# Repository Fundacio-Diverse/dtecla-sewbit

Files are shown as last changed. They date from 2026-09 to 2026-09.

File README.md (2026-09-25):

# sew:bit
## Una placa de expansión de código abierto que amplía las posibilidades del micro:bit para la informática textil y los dispositivos wearables en la educación primaria (K-6)
Sew:bit es una placa de expansión de código abierto para el BBC micro:bit, diseñada en el marco de un Fab Lab para facilitar la creación de dispositivos wearables y textiles electrónicos en la educación primaria (de infantil a 6.º de primaria).

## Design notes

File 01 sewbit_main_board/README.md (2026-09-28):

## Diseño
La placa sew:bit está diseñada usando el EDA open source Kicad en su versión 8.0. En la carpeta Diseño podréis encontrar el editable del mismo, así como el svg de las serigrafía.

Para más información sobre [Kicad](https://www.kicad.org/).

## Producción
La placa se puede fabricar en cualquier casa de fabricación de pcbs, los gerber que hay en la carpeta son los requeridos por JLCPCB en su [guía para exportar archivos de producción en Kicad 8](https://jlcpcb.com/help/article/how-to-generate-gerber-and-drill-files-in-kicad-8).

El edge connector de micro:bit SMD no está disponible, al menos a fecha de Junio 2026, en la lista de partes de JLCPCB y se ha de comprar independientemente, nosotros hemos probado:

- [Sparkfun](https://www.digikey.es/es/products/detail/sparkfun-electronics/17253/13282853)
- [Aliexpress](https://es.aliexpress.com/item/1005008738053304.html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)

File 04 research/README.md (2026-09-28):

Papers:
FAB 26 @Boston - Leirado, J., Domínguez, X., & Fuentemilla, S. (2026, July 31). Sew:bit: An Open-Source Expansion Board Extending the micro:bit for E-Textile and Wearable Computing in K-6 Education. Fab 26 "Reimagine the Future" Research Papers (FAB26), Cambridge, MA, USA. https://doi.org/10.5281/zenodo.21712564

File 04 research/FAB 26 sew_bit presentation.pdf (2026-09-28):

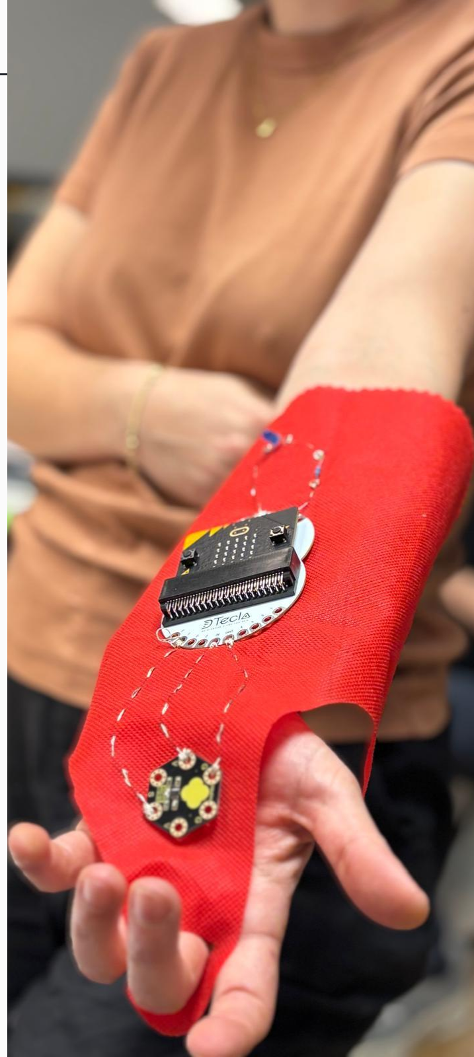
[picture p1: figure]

Julia Leirado - IAAC / Fab Lab Barcelona

# sew:bit

## An Open-Source Expansion Board Extending the micro:bit for E-Textile and Wearable Computing in K-6 Education

Xavier Domínguez - Fundació Diverse

Santiago Fuentemilla - IAAC / Fab Lab Barcelona

Micro:bit - E‑textiles - K-6 - Open hardware - Physical computing education - Digital Fabrication - Computational Making

Leirado, Domínguez & Fuentemilla (2026) — Design case study

# Contents

# Purpose of the paper

# Design/ methodology/ approach

# Data Sample

# Research limitations

# Practical implications

# Original value

Company Name | 2
01 | 05

02

03

06

07

# Findings

04

# Takeaway

08

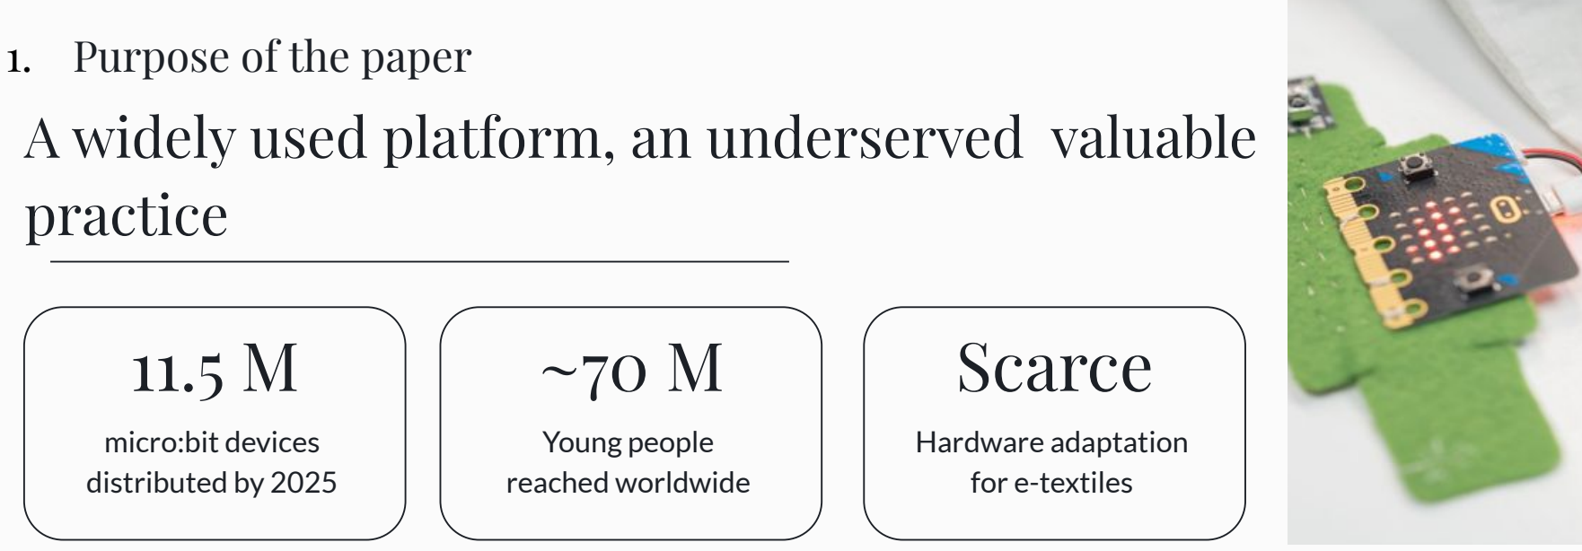
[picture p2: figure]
micro:bit devices distributed by 2025; 1. Purpose of the paper; practice; Young people reached worldwide; Hardware adaptation for e-textiles; Scarce

Leirado, Domínguez & Fuentemilla (2026) — Design case study | 3

# A widely used platform, an underserved valuable

E-textiles are a powerful route to equitable STEAM, engaging diverse learners — especially girls — by blending craft with code and circuitry (Buechley 2008; Rode 2015).

Yet the BBC micro:bit — the most adopted K-6 physical-computing platform — lacks hardware designed for textile-based making. LilyPad, Flora and Circuit Playground shaped wearable computing, but none adapt the micro:bit for the classroom stock schools already own.

Option | Pros | Cons
No additional components needed | Limited to 3 pins Board becomes permanent (must cut stitches to repurpose)

### Direct sewing of exposed connectors

Reusable: connect/disconnect BBC micro:bit without cutting stitches

### Crocodile clips (Kitronik)

### SewSimple (Feng et

al., 2025)

Flexible fabric extension for wearable integration
Large through-hole (TH) pads for beginner needles

Limited to 3 pins
Narrow holes incompatible with large beginner sewing needles

Limited to 3 pins
Not commercially available (Research)

# 1. Purpose of the paper

# No optimal way to adapt the micro:bit for e-textiles

### Keyestudio Honeycomb kit

Edge connector for reusability 10 pins for sensors/actuators Wide sensor/actuator range

Bottom connectors cause forward tilt (BBC micro:bit weight hinders wearables)
Some sensors redundant or too advanced for K-9 Missing beginner-friendly sensors

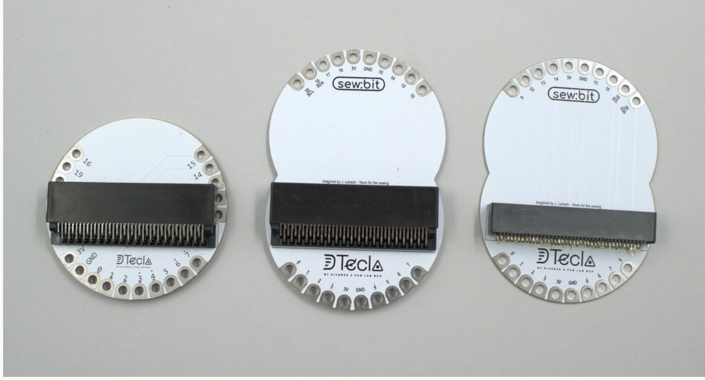
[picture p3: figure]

Sew:bit board | An open‑source expansion board that adapts the micro:bit for textile‑based making.

## Documented design case

| Iterative development within a Fab Lab context: decisions, failures, fixes.
Early findings | From deployments with K-6 students, teachers and makers on usability, accessibility and pedagogy.

01
02
03

# 1. Purpose of the paper

# Contribution of the paper

# 2. Design/ methodology/ approach

# A design case study, not a controlled evaluation

Iterative cycles of design → fabrication → workshop → reflection.
Iteration, repair and adaptation are treated as sources of design knowledge (Boling, 2010).
3 full cycles over 1 year, each: problem analysis · prototyping · workshop enactment · redesign.

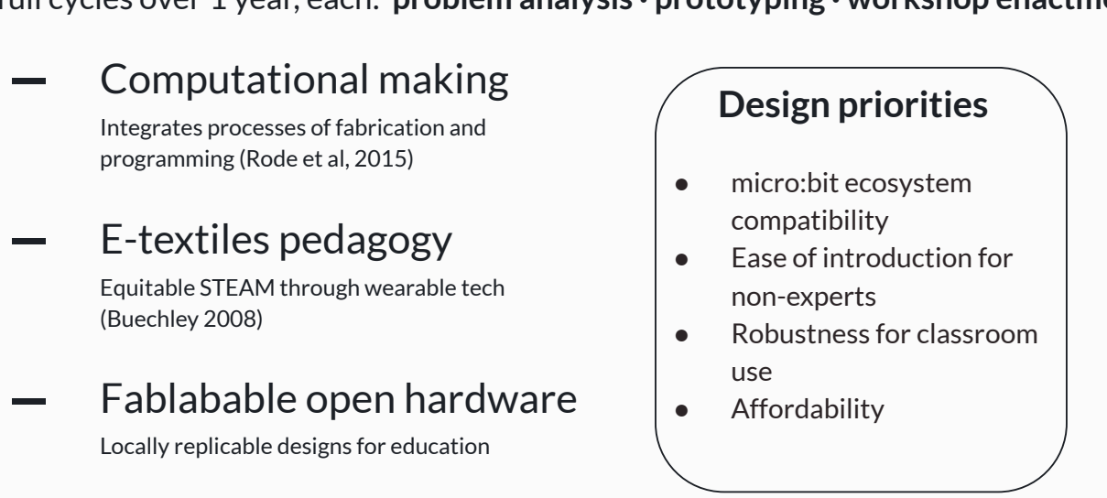
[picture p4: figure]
Computational making; Integrates processes of fabrication and programming (Rode et al, 2015); E-textiles pedagogy; Fablabable open hardware; Equitable STEAM through wearable tech (Buechley 2008); Locally replicable designs for education; ● micro:bit ecosystem compatibility ● Ease of introduction for non-experts ● Robustness for classroom use ● Affordability; Design priorities
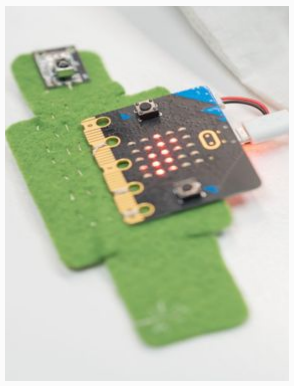
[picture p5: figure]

# 2. Design/ methodology/ approach

# Cycle 1: basic shield - Form factor first : a circular, sewable shield

- Aesthetics & accessibility — craft look (à la LilyPad); easy edge-connector insert/removal for multi-project reuse.
- Physical layout — circular shape → traces radiate from centre, spacing pads and reducing shorts.
- Sewability — oversized pads for large-hole needles; crocodile-clip friendly.

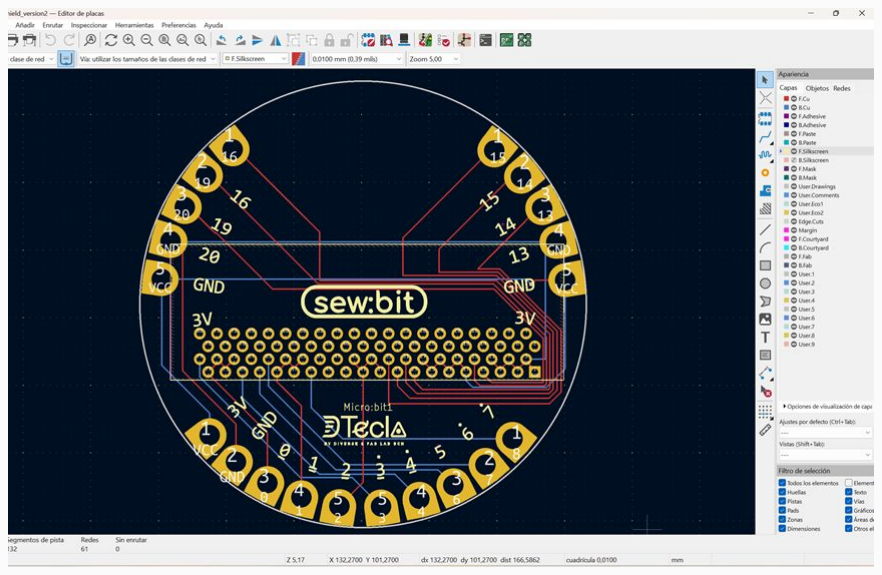
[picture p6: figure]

Workshop findings:
- TH edge connector too fine to mill locally → outsourced.
- Footprint error,
- pin occlusion,
- unstable on fabric.
- 10 prototypes.

Design - fabrication workflow:

# 2. Design/ methodology/ approach

# Cycle 2: two intersecting circles, top/bottom pins

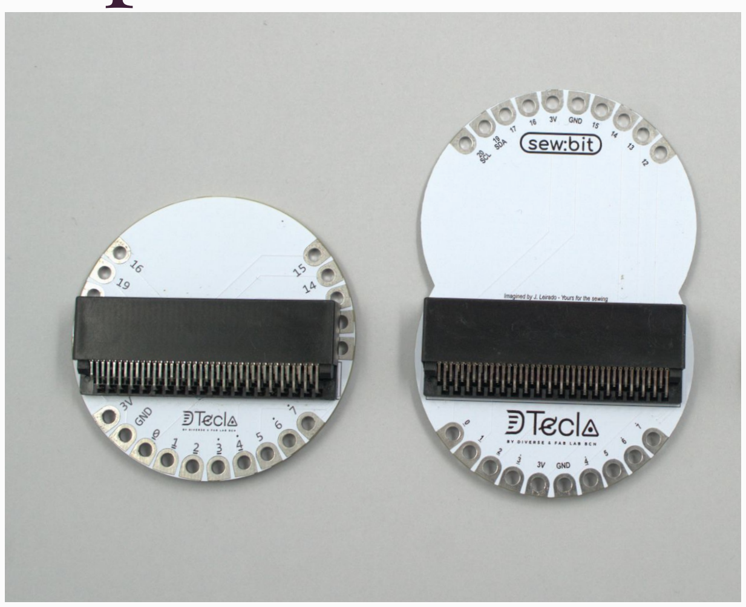
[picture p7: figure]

- Thinner board 1.6 → 1 mm (−37.5%) for a lighter feel.
- New shape from two intersecting circles — exposes all pins, keeps rounded aesthetics.
- Top/bottom split pins anchor stitching and stop forward tilt.
- Side gap holds a LiPo battery by geometry alone.

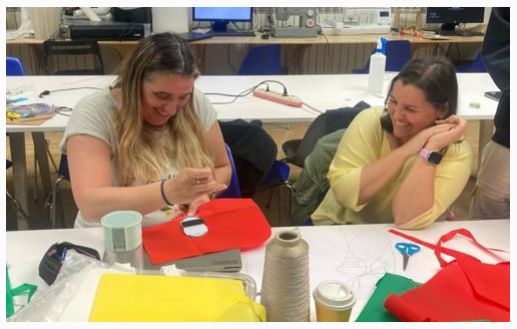
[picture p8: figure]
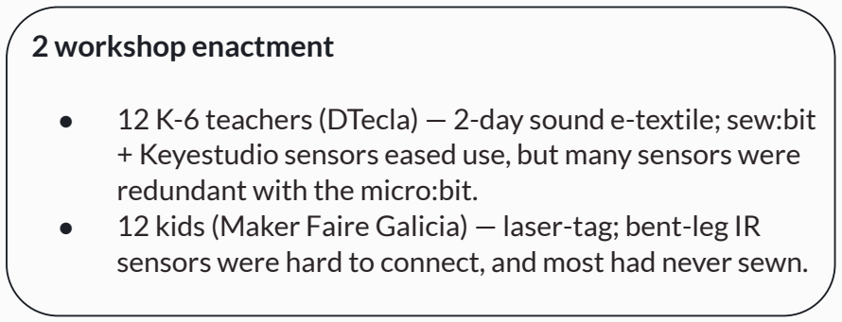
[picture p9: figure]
2 workshop enactment; redundant with the micro:bit.

- 12 K-6 teachers (DTecla) — 2-day sound e-textile; sew:bit + Keyestudio sensors eased use, but many sensors were
- 12 kids (Maker Faire Galicia) — laser-tag; bent-leg IR sensors were hard to connect, and most had never sewn.

# 2. Design/ methodology/ approach

# Cycle 3: Locally fabricable, with a sensor kit + perforated

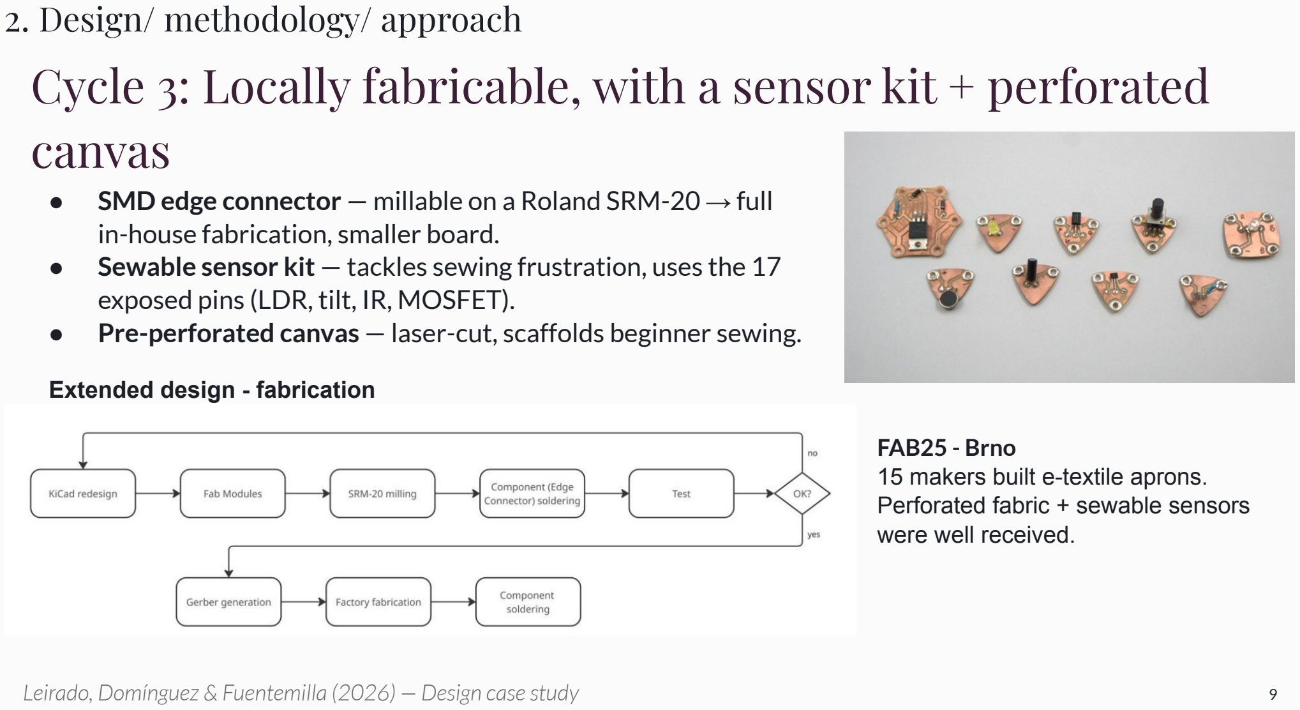
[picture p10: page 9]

# canvas

- SMD edge connector — millable on a Roland SRM-20 → full in-house fabrication, smaller board.
- Sewable sensor kit — tackles sewing frustration, uses the 17 exposed pins (LDR, tilt, IR, MOSFET).
- Pre-perforated canvas — laser-cut, scaffolds beginner sewing.

FAB25 - Brno
15 makers built e-textile aprons. Perforated fabric + sewable sensors were well received.

Extended design - fabrication workflow:

# 3. Data sample

# Workshop contexts as sources of design reflection

No formal data-collection study. Observations, informal conversations and workshop notes were used descriptively to inform each redesign.

Cycle | Pros | Participants
Cycle 1 | Fab Lab Bcn / Fundació Diverse staff | 3
Cycle 2.1 | K-6 teachers (Dtecla)
Cycle 2.2 | Children (Maker Faire Galicia)

12

12

Cycle 3 | Maker community (FAB25) | 15

## Workshop purpose

Internal prototype testing & design refinement

Explore classroom-oriented e-textiles

Explore beginner use of the prototype

Explore fablable sensor & board use

# 4. Findings

# Four recurring design insights

Hardware
usability &
sewability

Learning &
engagement

02

Classroom
integration &
scaffolding

03

Fab Lab reception
& replication
01 | 04

By Cycle 3,
pre-perforated fabric
+ dedicated sewable
sensors reduced
shorts — reliable
circuits within
1.5-hour workshops.

Teachers felt
confident to reuse
the board; kids
personalised
laser-tag wearables;
makers built diverse
apron interactions.

Teachers valued
micro:bit
compatibility but
flagged time limits,
need for
pre-packaged kits
and basic sewing
gaps.

Fab25 makers
responded positively
and asked for full
docs:
KiCad/Gerber/BOM,
lesson plans,
parametric files.

# 5. Research limitations

# Situated insights, not generalizable results

## Bounds of this work

- Workshops sat within
connected Fab Lab / maker
networks, not independent
schools.
- Modest number of enactments — no controlled comparison or statistical generalization.
- Prototype stage: not studied at manufacturing scale or in
longitudinal classroom use.

## Where to go next

- Deploy across a broader, more diverse range of Fab
Labs and schools.
- Formal classroom studies with a clear methodology.
- Comparative testing against commercial kits.
- Longitudinal use + reflections from teachers, makers and
children.

# 6. Practical implications

# What sew:bit offers each audience

Fablab & makerspaces | SMD connector → full in-house milling of double-sided boards. Download the complete repo (KiCad, Gerber, BOM, assembly) and adapt to regional parts.
K-6 classroom teachers | Extends existing micro:bit inventory — minimal new purchases. A learning journey from perforated-fabric sensor projects to curriculum-integrated work.

## micro:bit e-textiles designers

| Four transferable design principles to guide future wearable hardware for the micro:bit.

01
02
03

# 6. Practical implications

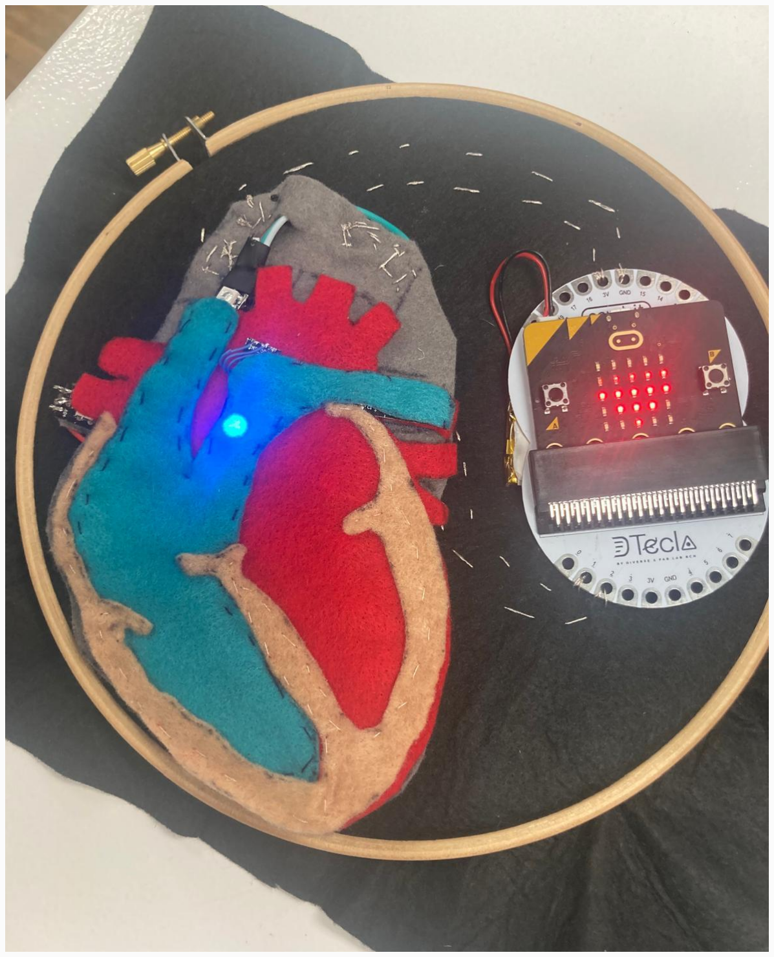
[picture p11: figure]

# What we'd tell the next hardware designer

- Top/bottom pin distribution: Prevents forward tilt; keeps natural fabric drape when sewn.
- Oversized sewable pads (≥3 mm): Fit large-hole beginner needles and crocodile clips for prototyping.
- Millable SMD edge connector: Enables local Fab Lab production (Roland SRM-20 compatible).
- Modular sensor kits: Ready-to-sew sensors optimised for pedagogical projects; less improvisation.

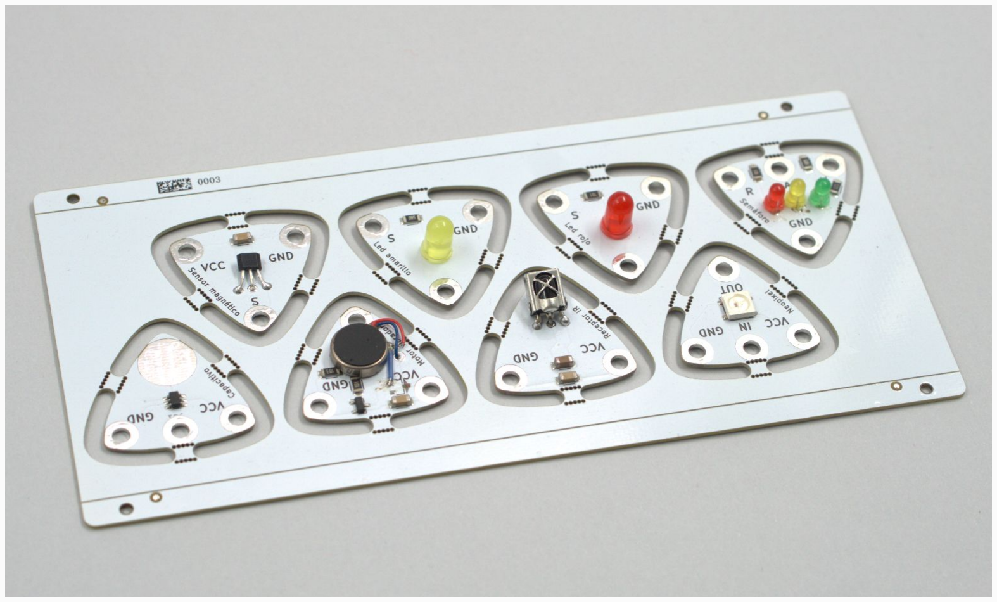
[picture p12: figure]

# 6. Practical implications

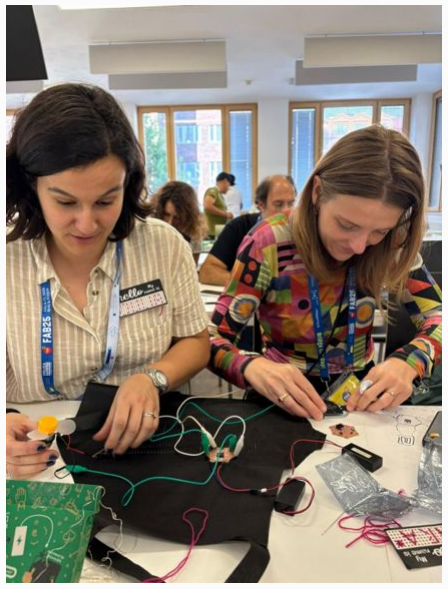
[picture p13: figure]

# A fablable micro:bit e-textile ecosystem

- Three documented Fab Lab iterations — failures (pin occlusion, forward tilt, sensor leg-bending) and their fixes, with full replication files.
- Four micro:bit-specific design principles for e-textile hardware.
- A K-6 pedagogical pathway from scaffolded sensor exploration to curriculum projects — addressing a recognised research gap.

## Novel elements

# 8. Takeaways

# sew:bit brings e-textiles to the world's most deployed

classroom microcontroller: openly, and fabricable anywhere.

Open by design KiCad · Gerber · BOM · assembly guides · MakeCode · parametric files — for local adaptation and replication.

Acknowledge
Developed within the DTecla project — Fundació Diverse × Fab Lab Barcelona — supporting STEAM/maker education in vulnerable school environments. Thanks to the children, teachers and makers across the three workshops, and to Fab Lab Barcelona staff (Josep, Dani, Adai).

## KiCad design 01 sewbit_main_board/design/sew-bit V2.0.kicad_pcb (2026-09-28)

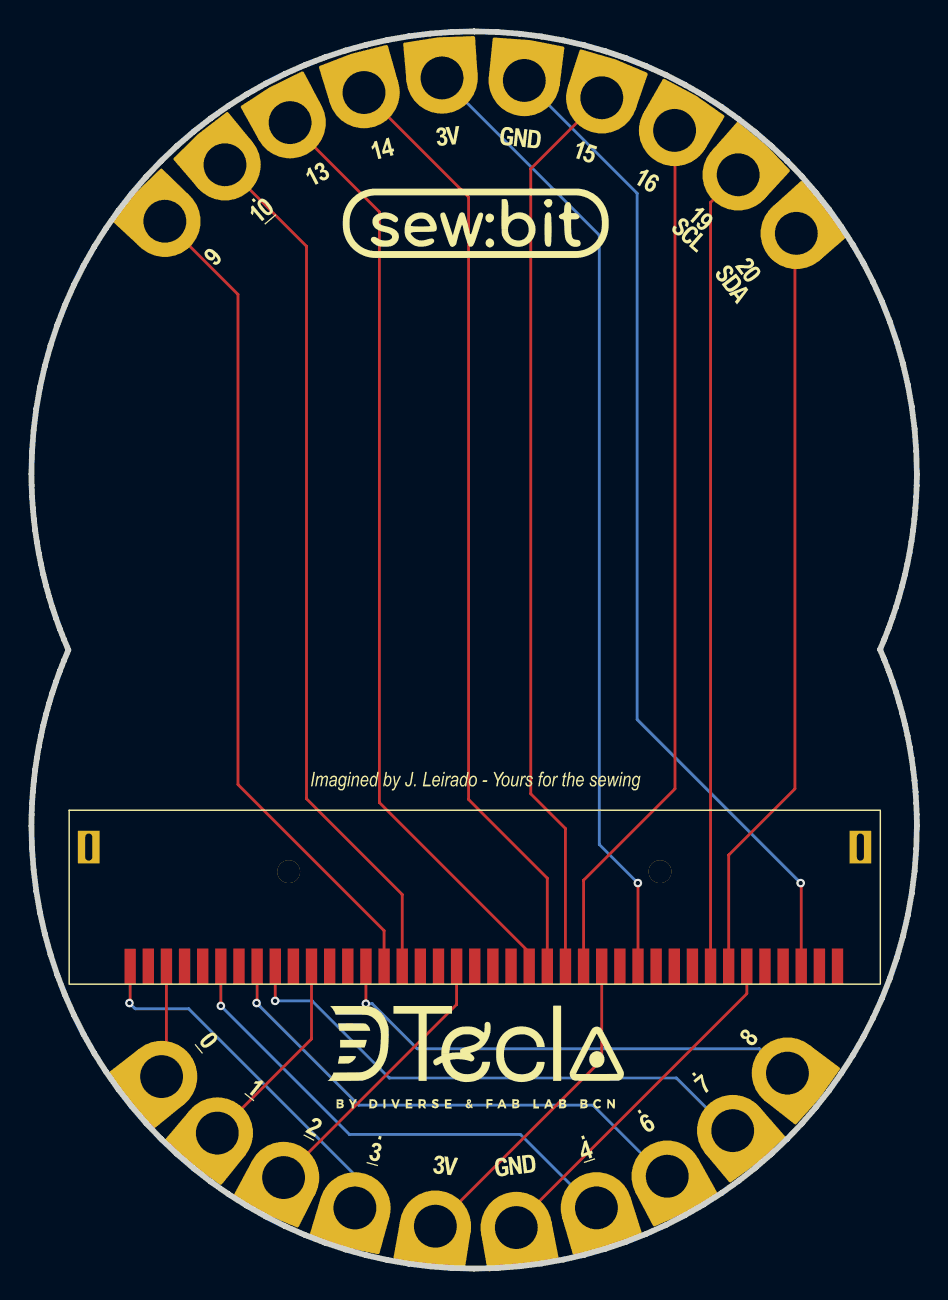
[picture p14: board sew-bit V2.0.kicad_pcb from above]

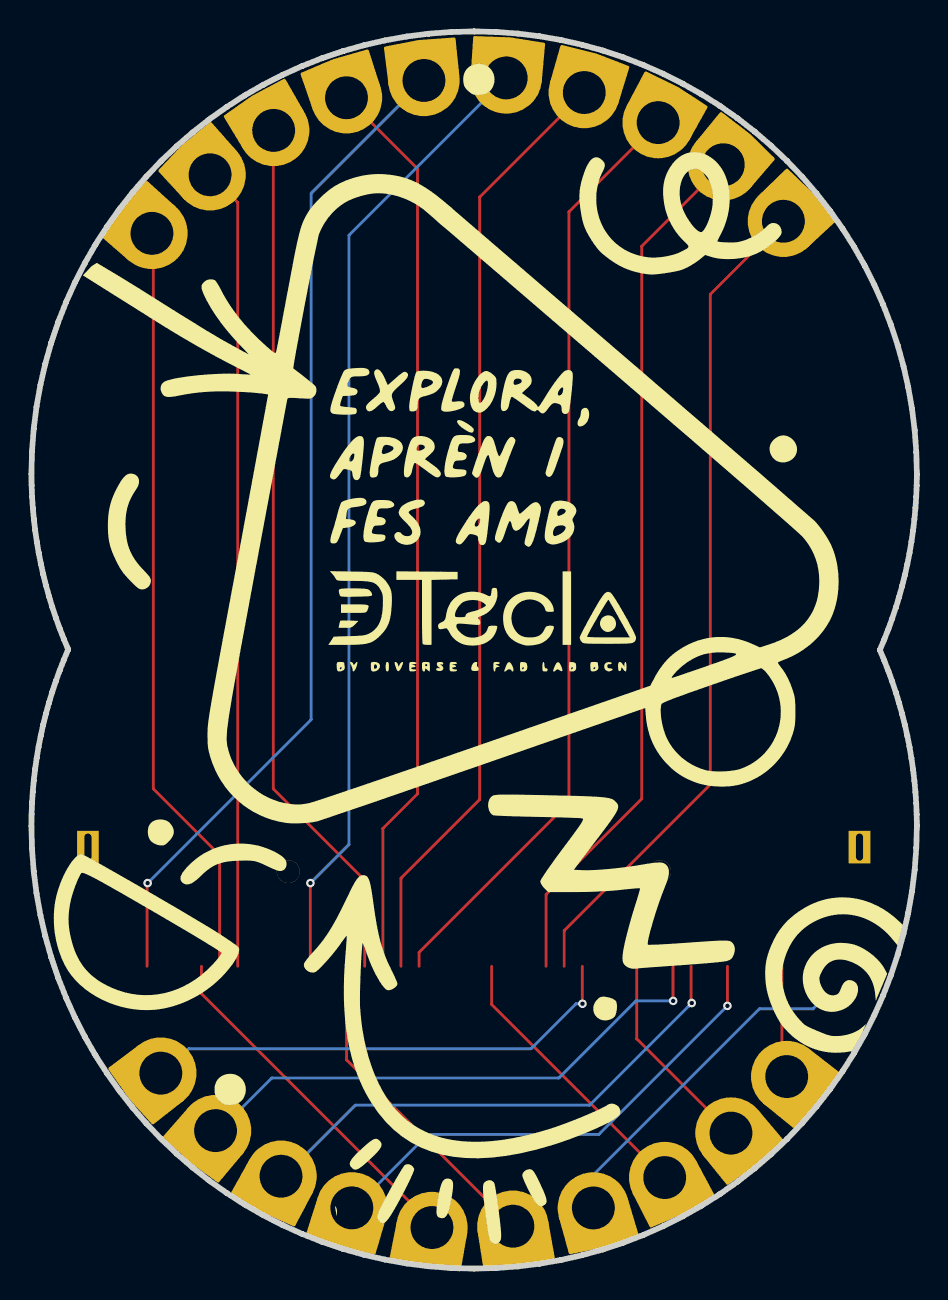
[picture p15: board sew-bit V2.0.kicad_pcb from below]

Board: 2 copper layers, 62.0 x 86.6 mm, 5 parts (2 on the bottom side), 18 nets.

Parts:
Micro:bit1: Microbit edge conector 2_SMD
U1, U2, U3, U4: pads x5

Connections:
0: Micro:bit1.2 (P0), Micro:bit1.3 (P0), Micro:bit1.4 (P0), Micro:bit1.5 (P0), U3.1
1: Micro:bit1.10 (P1), Micro:bit1.11 (P1), Micro:bit1.12 (P1), Micro:bit1.13 (P1), U3.2
2: Micro:bit1.19 (P2), Micro:bit1.20 (P2), Micro:bit1.21 (P2), Micro:bit1.22 (P2), U3.3
3: Micro:bit1.1 (P3), U3.4
4: Micro:bit1.6 (P4), U4.4
6: Micro:bit1.8 (P6), U4.3
7: Micro:bit1.9 (P7), U4.2
8: Micro:bit1.14 (P8), U4.1
9: Micro:bit1.15 (P9), U2.5
10: Micro:bit1.16 (P10), U2.4
13: Micro:bit1.23 (P13_SCK), U2.3
14: Micro:bit1.24 (P14_MISO), U2.2
15: Micro:bit1.25 (P15_MOSI), U1.2
16: Micro:bit1.26 (P16), U1.3
19: Micro:bit1.33 (P19_SCL), U1.4
20: Micro:bit1.34 (P20_SDA), U1.5
GND: Micro:bit1.35 (P21_GND), Micro:bit1.36 (GND), Micro:bit1.37 (GND), Micro:bit1.38 (GND), Micro:bit1.39 (GND), Micro:bit1.40 (P22_GND), U1.1, U4.5
VCC: Micro:bit1.27 (P17_3v3), Micro:bit1.28 (3v3), Micro:bit1.29 (3v3), Micro:bit1.30 (3v3), Micro:bit1.31 (3v3), Micro:bit1.32 (P18_3v3), U2.1, U3.5

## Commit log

2026-09-25 Añadí README inicial en la raíz del proyecto
2026-09-25 he creado estructura de carpetas
2026-09-28 Añadido el proyecto de kicad con el esquematico y el diseño pcb junto ocn el diseño de la serigrafia
    [sew-bit V2.0.kicad_pcb, sew-bit V2.0.kicad_sch]
2026-09-28 añadidos archivos de fabricación de la sew:bit
    [sew-bit V2.0-B_Cu.gbl, sew-bit V2.0-B_Mask.gbs, sew-bit V2.0-B_Paste.gbp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]
2026-09-28 Añadida info sobre el diseño y fabricación de la placa principal
2026-09-28 añadidos links de compra del edge conector en el README de la placa principal
